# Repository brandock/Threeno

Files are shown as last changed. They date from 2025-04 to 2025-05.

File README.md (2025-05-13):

# Threeno

**Threeno** is a family of through-hole, Arduino-compatible boards that came out of my own learning process as I dove deeper into low-power wireless sensor nodes. These boards were inspired by the amazing work of Jean-Claude Wippler (JeeLabs), Felix Rusu (LowPowerLab), the OpenEnergyMonitor project, Nathan Chantrell’s TinyTx, and many others. Threeno is not meant to replace any of those designs—rather, it's a personal attempt to bring together what I’ve learned from them into a format that helped me prototype and understand more deeply. They’ve been useful to me as learning tools and prototypes—and maybe they can help others explore this ecosystem, too.

I wanted a board I could use to explore this whole ecosystem—JeeLib, OpenEnergyMonitor, RFM69 radios, and the new AVR parts supported by Spence Konde's cores—but with a familiar Arduino Uno shield footprint. I didn’t want to rely on breadboards anymore. Too often, my breadboard connections were the reason things didn’t work. So Threeno took shape as a set of hand-solderable boards using plated-through-hole parts that anyone with a soldering iron could build and experiment with.

## Objectives

These design goals shaped where and how pins are broken out on the boards:

- **Familiarity**: Match the footprint of the Arduino Uno for compatibility with Uno shields and known layouts.
- **Pin Position Parity**: Line up SPI, Serial, I²C, and other common peripherals with their usual locations on the Uno.
- **Through-hole Focus**: Use PTH parts wherever possible to keep things accessible. (HopeRF radios are technically SMD, but easily hand-soldered.)
- **Proven Components**: Include parts and patterns from designs by JeeLabs, Low Power Labs, OpenEnergyMonitor, and TinyTx—such as the MCP1702 regulator and the multi-transceiver RFM footprint.
- **Stock Arduino Tooling**: Use standard Arduino board managers—no Threeno-specific tools required. ATmega328P boards use the built-in Uno target; AVR128DB28 and ATtiny84 boards use Spence Konde’s DxCore and ATTinyCore.
- **Onboard Radios**: Including the HopeRF transceivers on the board makes prototyping wireless sensors a lot easier. These parts are somewhat notoriously difficult to breadboard, so having it soldered on in a proven way takes the guess work out of that part of your prototype. Other boards, such as Felix Rusu's Moteino, also take this approach in compact and polished designs.
- **Low Power**: Use the techniques used by Rusu, JCW, and OpenEnergyMonitor to make the boards run at very low power, with single-digit uA achievable in deep sleep mode.

## Ecosystem

Threeno boards are designed to work naturally with:

- [**JeeLib**](https://github.com/jeelabs/jeelib) by Jean-Claude Wippler (JCW)
- [**OpenEnergyMonitor**](https://openenergymonitor.org/) by Glyn Hudson, Trystan Lea, Robert Wall, and many others
- [**LowPowerLab’s low-power IoT project ecosystem**](https://lowpowerlab.com) by Felix Rusu
- [**Arduino IDE**](https://www.arduino.cc/en/software) with these board cores:
  - [**DxCore**](https://github.com/SpenceKonde/DxCore) – for AVR DB series
  - [**ATtinyCore**](https://github.com/SpenceKonde/ATTinyCore) – for ATtiny84

## Threeno Alternatives

Threeno tries to fill a specific niche: a set of through-hole, hand-solderable boards with onboard radios that integrate smoothly into the JeeLib and OpenEnergyMonitor ecosystems. But depending on your needs, one of these other boards might be a better fit:

- [**Moteino**](https://lowpowerlab.com/guide/moteino/) – The original Arduino + transceiver board. If you want an Arduino UNO-compatible board with a HopeRF transciever onboard, if you were not interested in soldering your own board, and if you didn't need the classic Arduino board-shape, you would clearly choose a Moteino over a Threeno. Compact, preassembled, with a great set of shields and sketches. Part of an IoT ecosystem of its own, with a great user community and great support from Felix Rusu. You should probably just get a Moteino or two regardless. 
- [**JeeNode**](https://web.archive.org/web/20201130081805/https://jeelabs.org/docs/hardware/jnclassic/) – A classic by JCW. [You can use the JeeNode USB as a RF-to-serial gateway.](https://community.openenergymonitor.org/t/receiving-jeelib-classic-and-lowpowerlab-in-parallel/22563) JCW has numerous plugin boards with various parts and sensors. It is a clever system that is different than Arduino sheilds, and makes a ton of sense. I have a classic JeeNode and love it.
- [**Azduino**](https://azduino.com) – The latest and greatest AVR microcontrollers, on convenient breakout boards from Spence Konde, who is making the Arduino cores for them.
- [**ESP32/ESP8266**](https://en.wikipedia.org/wiki/ESP32) – Excellent for Wi-Fi/Bluetooth, though less ideal for ultra-low power, which is one of the goals of the Low Power Lab, the JeeNode, and the OpenEnergyMonitor ecosystems.
- [**EVB RFduino**](https://dwmzone.com/en/hoperf/67-657-hoperf-dk-evb-rfduino-board.html?gQT=1) - I don't know much about this board, but it is apparently an Arduino Uno-compatible board with HopeRF radio pre-assembled. So if you (a) needed the Uno footprint (so Moteino wasn't an option) (b) didn't need onboard SPI flash memory option (RFduino apparently lacks one) (c) didn't want to solder together your own kit, this might be a board to investigate.

Each of these brings something different to the table—Threeno just aims to make it easier for people (especially soldering hobbyists) to experiment in this space with familiar tools and components.

## Meet the Boards

### [Threeno Tx (ATmega328P)](ThreenoTx.md)
A classic 3.3V UNO-style board with onboard RFM69CW and FTDI or ISP programming.


### [Threeno Tiny Tx (ATtiny84)](ThreenoTinyTx.md)
Minimal and battery-friendly. Based on the ATtiny84, a nod to Nathan Chantrell’s TinyTx.


### [Threeno DB28 Tx (AVR128DB28)](ThreenoDB28.md)
A modern AVR with UPDI programming, MVIO, and Uno-compatible layout.
IMG_4648 (1)

## Getting the Boards

- **Download Eagle files** and generate Gerbers
- **Order from Seeed Fusion**
- **Use the BOM** to order parts from DigiKey or Mouser

Each board page includes soldering guides and full part lists.

## Useful Tools

- [**FlexyTx Shield**](https://lowpowerlab.com/shop/flexytx) – Mount and test RFM69CW radios easily
- [**Evil Mad Scientist ISP Shield**](https://shop.evilmadscientist.com/productsmenu/652) – For burning bootloaders to raw AVRs

## Developing with Threeno

Use Spence Konde’s Arduino cores:

- [DxCore](https://github.com/SpenceKonde/DxCore) – for AVR128DB28
- [ATtinyCore](https://github.com/SpenceKonde/ATTinyCore) – for ATtiny84/85

For ATmega328P-based boards, select “Arduino Uno” in the IDE.

## License

This project is licensed under the GNU General Public License v3.0.

You may copy, distribute, and modify this software under the terms of the GPLv3.

See the full license at: https://www.gnu.org/licenses/gpl-3.0.en.html

---

This project is a thank you to the makers who built the boards I learned from.

– Brandon Baldock

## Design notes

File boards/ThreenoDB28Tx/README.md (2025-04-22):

# ThreenoDB28Tx

→ **Why this board?**  _(fill in)_  
→ **Pin‑out philosophy**  _(fill in, or copy from Board‑X‑PinoutPhilosophy.md)_  
→ **Build steps**  `make gerbers` → order → solder → program → blink :)

| Quick links |
|-------------|
| [BOM & ordering notes](docs/BOM.md) |
| [Build guide](docs/Build.md) |
| [Programming steps](docs/Program.md) |
| [Variants](docs/Variants.md) |
| [Example sketches](firmware/) |

```text
hardware/   KiCad or Eagle files
firmware/   PlatformIO / Arduino sketches
docs/       Markdown docs (exported as wiki or GitHub Pages)
```

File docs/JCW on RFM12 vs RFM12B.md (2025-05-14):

This article by RCW is interesting because he contends that the RFM12B won't be damaged by 5V. 

It can be found [here](https://web.archive.org/web/20210924000509/https://jeelabs.org/2009/05/06/rfm12-vs-rfm12b-revisited/index.html).

It is a follow-up to an initial article (also below) that can be found [here](https://web.archive.org/web/20210923233828/https://jeelabs.org/2009/04/29/rfm12-vs-rfm12b/index.html).

----------------

## RFM12 vs RFM12B – revisited ##
_In AVR, Hardware on May 6, 2009 at 00:01_

Now that the RFM12 is [working](https://jeelabs.org/2009/04/29/rfm12-vs-rfm12b/index.html), here’s the list of differences between RFM12 and RFM12B I’ve come across:

- The RFM12 works up to 5V, the RFM12B only up to 3.8V (but it won’t be damaged by 5V).
- The RFM12 needs a pull-up resistor of 10..100 KΩ on the FSK/DATA/nFFS pin, the RFM12B doesn’t.
- The RFM12 can only sync on the hex “2DD4” 2-byte pattern, the RFM12B can sync on any value for the second byte, not just D4.

More differences, found by Reinhard Max:

- The B version can be set to a single sync byte.
- The “PLL setting command” (CCxx), which only exists on the RFM12B.
- Different values for RX sensitivity and TX output power.
- A slightly different formula to calculate the time of the Wake-Up Timer.

Here is the back of the module, RFM12 on the left, RFM12B on the right:



_(these also happen to be for different frequency bands, as you can see)_

And here is the front view, with RFM12 on the _right_ and RFM12B on the _left_ this time:



The RFM12 unit on the right has a pull-up resistor added on top – note also the exposed pads at the top.

Note how the alignment of the solder pads on the JeeNode PCB is a bit off – these are v1 PCB’s, the v2 PCB’s have better alignment.

## RFM12 vs RFM12B ##
_In AVR, Hardware on Apr 29, 2009 at 00:01_

Here’s an RFM12 433 MHz module from Pollin, hooked up to an Arduino Duemilanove:



One major difference between the RFM12 and the RFM12B is that the RFM12 can run at 5V, whereas the maximum operating voltage for the RFM12B is 3.8V (it can withstand up to 6V, which is good to know).

Alas, there seems to be some other difference which eludes me, because the RFM12 hooked up in the above picture only seems to be able to send. The RF12 demo code, which works fine for send and receive on RFM12B’s, seems to do something wrong. Same behavior with another RFM12 module – so it looks like this is not due to a broken module. Send works, but nothing is coming in other than occasional garbage data.

The transmit part works fine when sending to an RFM12B, also in OOK mode: the RFM12 successfully controls both 433 and 868 MHz units (KAKU and FS20, respectively). _But as packet receiver for other RFM12 or RFM12B modules … no joy so far._

Weird. Tips, anyone? Please let me know.

**Update** – Thanks to R. Max’s comment below, the problem has been solved: the RFM12 does not support arbitrary 2-byte sync patterns, _it has to be 0x2D + 0xD4_ – then it works fine!

**Update 2** – _See also the [RFM12 vs RFM12B revisited](https://jeelabs.org/2009/05/06/rfm12-vs-rfm12b-revisited/index.html) page for a list of differences._

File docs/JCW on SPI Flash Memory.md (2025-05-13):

Some Threeno Tx boards have the option of onboard SPI flash memory, for compatibility with Moteino firmware and over-the-air programming developed by Felix Rusu of LowPowerLab.

JCW wrote in his blog about SPI flash memory, and I found it instructive, so I repost it here. You can also find it [here](https://web.archive.org/web/20221230224953/https://jeelabs.org/2015/04/15/dataflash-via-spi-2/index.html).

## Dataflash via SPI ##
_In Book on Apr 15, 2015 at 00:01_

One of the things I’m going to need at some point is additional flash memory. Since the simplest way these days to add more memory is probably via SPI, that’s what I’ll use.

This week’s episode is about connecting an SPI chip, implementing a simple driver, code re-use, the hidden dangers of solderless breadboards, and point-to-point soldering:



Hooking up a dataflash chip – Wed
Accessing SPI memory – Thu
Too much capacitance is bad – Fri
Soldering one-off SMD circuits – Sat
The end result is several megabytes of extra storage, using only 4 I/O pins. Data logger? Serial port audit? Storage for audio, video, images? Your next novel? _It’s all up to you!_

Hooking up a dataflash chip
Flash memory has taken over the world, covering an amazing range of memory needs:

- microcontrollers: _kilobytes_
- dataflash chips: _megabytes_
- USB- and (µ)SD cards: _gigabytes_
- SSDs in laptops and servers: _terabytes_

They all maintain their contents for many years and can be erased and re-written tens of thousands of times. Long gone are the days of core memory and battery backed-up RAM.

Not only that, a tiny dataflash chip such as this one from Winbond costs less than €2:



That gets you up to 16 megabytes of non-volatile storage, and the data is available faster than most most µCs can read them, with SPI clock rates up to 100 MHz. When connected in “Quad-SPI” mode, some µCs can in fact access 4 bits in parallel, giving a read-access rate of over 50 _Mbyte_ per second. That’s _random_ access: no rotational or seek delays in sight!

Writing is another matter. Usually, data can be written in units from 1 byte to one “page” (256 bytes, typically). Programming will normally take between 1 and 5 milliseconds – this is several orders of magnitude slowdown compared to the above sub-µs read timing.

It gets worse: you can’t just write anything anywhere – you can only turn a “1” bit into a “0” bit when programming any part of memory. After that, flash memory needs to be _erased_ before re-programming it further. An erase cycle resets part or all of memory to 1’s.

The bad news? Erasure can only be done in _sectors_ (or _segments_) of 4 Kb, usually (as well as a few larger units, all the way up to a full chip-erase).

The _really bad_ news? Erasing a segment can often take some 100 ms, with a full chip erase sometimes requiring several _minutes!_ – and after many erasures, these times will increase. During this time, the flash chip will be _busy_ (though there are ways to suspend/resume it).

The exact specs differ somewhat between chip families and manufacturers.

But as with the RomVars implementation described earlier, we can use tricks to make this delay less important. The basic idea is to keep one or more “pre-erased” sectors available, and to start a new erasure when the amount of erased memory gets too low. This requires keeping track of what is in use, and “garbage collecting” sectors to remove unused gaps.

But first, let’s just hook up such an SPI dataflash chip, in this case the Winbond W25Q64 – a 64 Mbit chip, i.e. 8 MB. It can erase sectors of 4, 32, and 64 KB, as well as the entire chip.

It’s easier to do this with an LPC812 than an 8-DIP LPC810 with only 6 I/O pins: with the LPC810, 4 of these will be needed for SPI, making it hard to reserve the 4 I/O pins needed for uploading as well. Besides, the LPC812 (at least some models) supports two separate SPI peripherals – which makes it much simpler to interface to both dataflash and a radio:



Note the use of a _breakout board_ again, to allow using this SMD chip on a breadboard.

The pins (numbered in counter-clockwise order) are connected as follows:

- pin 1: /cs    : PIO0_13
- pin 2: dout   : PIO0_7
- pin 3: /wprot : not connected
- pin 4: gnd    : ground
- pin 5: din    : PIO0_3
- pin 6: clk    : PIO0_2
- pin 7: /hold  : not connected
- pin 8: vcc    : 3.3V

The write-protect and hold pins are not used, and have an internal pull-up.

Note that actual GPIO pin choices are fairly arbitrary, since we can connect them all up as needed through the LPC8xx’s _switch matrix_ (except PIO0_10 and PIO0_11).

PIO0_2 and PIO0_3 are reserved for SWD hardware debugging on power-up, so the SWD functionality needs to be disabled to allow re-using them as ordinary I/O pins.

It’s probably good to point out here that most dataflash memory chips can only work with voltages up to 3.6V (and some not even that). _These chips may not be connected to 5V!_

Next, we’ll need some code to handle the SPI communication and verify that it all works.

## Accessing SPI memory ##
SPI is easy to interface to. That’s because the signalling is quite simple:



There’s a _master_ side (in this case, the µC), which is in control of the ENABLE, CLOCK, and MOSI pins, and there’s a _slave_ side (the dataflash chip), which controls the MISO pin (but only when ENABLE is low).

When ENABLE goes low, the master puts bits on the MOSI (“master out, slave in”) pin, and toggles the clock to shift each bit out to the slave. At the same time, it listens on the MISO pin (you guessed it: “master in, slave out”) and shifts the same number of bits in.

Usually the master first needs to send one or more bytes, so it ignores what comes back during those initial clock cycles. Then, it sends out 0’s and toggles the clock pin further to read back what the slave puts on the MISO pin. When done, the ENABLE pin is set to “1” again. All very simple stuff, even in software.

Unlike I2C, this is not a pure “bus”, in the sense that you can’t simply add more chips in parallel. Well, three of the pins _can_ and should be connected in parallel to all the slaves, but each slave will need a _separate_ ENABLE pin. In this example, there’s just one slave.

Most µCs have hardware support for SPI. This allows them to perform very fast signalling, much faster than software would be able to toggle and read out pins.

In the LPC8xx, the maximum speed for the master is the same as the µC’s clock speed, i.e. 12 MHz on power up, and 30 MHz when the PLL has been set up appropriately. Once set up, sending out and reading back two bytes using the LPC’s SPI hardware is trivial:

```c#
uint16_t xfer16 (uint16_t out) {
  addr()->TXDATCTL = SPI_TXDATCTL_FLEN(16-1) | SPI_TXDATCTL_EOT | out;
  while ((addr()->STAT & SPI_STAT_RXRDY) == 0)
    ;
  return addr()->RXDAT;
}
```

The LPC8xx hardware will set ENABLE to “0”, shift the data out and in using the CLOCK pin, and set ENABLE to “1” when done. At 12 MHz, this will all happen in less than 1.5 µS.

In the above example, three transfers can be seen: send 0x05 (result 0x00), send 0x35 (result 0x00), and send 0x9F (result 0xEF). These all access status and info registers.

SPI is a very common interconnect mechanism, and is also used by the RFM12/RFM69 wireless modules. In fact, we already have a _generic_ SPI bus driver in the embello repository on GitHub. It was designed to be easily re-used for different tasks.

And since SPI flash is a common mechanism, it’s a good idea to allow re-use of that code as well. Such an “SPI flash” driver can also be found on GitHub. Note that the SPI _bus_ driver is LPC8xx specific, but the SPI _flash_ driver built on top is not – it merely embodies the logic specific to the dataflash chip we’re using, _not_ how to talk to it for a particular µC.

With this code, we can now easily access our dataflash memory, using code such as:

```c#
#include "spi_flash.h"

SpiFlash<SpiDev0> spif;

int main () {
  ...
  spif.init();
  printf("0x%x\n", spif.identify());
  ....
  spif.eraseSector(...);
  spif.program(...);
  spif.read(...);
  ...
}
```

The SpiFlash<SpiDev0> is a C++ template notation, saying: define an object of the SpiFlash class, _specialised_ to use the SpiDev0 class as its bus access mechanism. Where SpiDev0 is in turn shorthand for SpiDev<0>, i.e. use the SPI0 hardware interface, of the two present in the LPC812 we’re using.

A simple test application can be found here. It erases a few sectors, programs a few pages, and then reads back the data a few times.

So, in _theory_, this stuff is trivial. We should expect this to work perfectly, right?

_Yes and no_… the “Channel 0” pin in the image above is a dangling wire, which happened to be attached to the 8-bit logic analyser (a €10 unit from eBay). Surprisingly, it returns some pulses. This is worrying – we seem to be picking up _stray_ signals from nearby wires.

_As you’ll see, there is some trouble ahead due to this and other unexpected side-effects._

## Too much capacitance is bad ##

The test code for the SPI flash erases sectors 0..9 (i.e. the first 40 KB), and then programs some values into the first 10 _pages_ (i.e. bytes 0..2559). Each page gets three values: N * 11, N * 22, and N * 33 – some of these values will end up different due to 8-bit truncation.

This is what a _good_ read-back of the first 11 pages should look like:

    #0: 0,0,0 @ 491 ms
    #1: 11,22,33 @ 493 ms
    #2: 22,44,66 @ 495 ms
    #3: 33,66,99 @ 496 ms
    #4: 44,88,132 @ 498 ms
    #5: 55,110,165 @ 501 ms
    #6: 66,132,198 @ 503 ms
    #7: 77,154,231 @ 505 ms
    #8: 88,176,8 @ 507 ms
    #9: 99,198,41 @ 509 ms
    #10: 255,255,255 @ 511 ms

The last value on each line is the clock time since startup (SPI is not running at max speed). Also, the last line shown above comes from a page which has been erased but not written to, and as you can see, it’s all 0xFF’s, i.e. all “1” bits.

Unfortunately, the _real_ test results are not consistent at all on the breadboard setup:

    #0: 0,128,128 @ 608 ms
    #1: 0,128,128 @ 610 ms
    #2: 0,128,128 @ 612 ms
    #3: 33,66,227 @ 614 ms
    #4: 44,216,132 @ 616 ms
    #5: 55,110,165 @ 618 ms
    #6: 66,132,198 @ 621 ms
    #7: 77,154,231 @ 623 ms
    #8: 88,176,136 @ 625 ms
    #9: 99,198,169 @ 627 ms
    #10: 255,255,255 @ 629 ms

Keep in mind that this is serial data, and for some reason, MISO is receiving all 0’s, or a 1 followed by 0’s on those first three pages. So some signal levels seem to be _wrong!_

The problem must be either a voltage or a timing issue, since the chip is clearly working, i.e. receiving and returning data “more or less” as expected. The software too must be doing its thing – again, we’d never be able to erase / program / read back _anything_ if it weren’t!

This is a typical hardware issue. In fact, it’s a fundamental electrical problem. Digital logic is all about 1’s and 0’s, and we’re not seeing the values we expect. At least not consistently.

An intermittent problem with voltage / timing (in reality, it’s _both_) points to an issue with “signal integrity”. What _should_ be a clean pulse on the wire, isn’t. It can be quite tricky to analyse such problems – even just hooking up an oscilloscope probe might affect the signal.

But there’s one easy way to find out if we’re looking in the right direction: build the same circuit again with a substantially different electrical configuration and see how it compares:



As you can see, this dataflash chip was soldered directly onto the back of an LPC812 board (from [eBay](https://web.archive.org/web/20230401203300/http://www.ebay.com/itm/151628723373)). And sure enough: it works flawlessly, at full 12 MHz speed. _Bingo!_

_So what’s going on here?_

It turns out that the culprit is the combination of a high-speed dataflash chip and our solderless breadboard. From the Winbond W25Q64 datasheet:



The maximum specified load capacitance is only 30 pF: these SPI slave chips are meant to be placed very close to the SPI master, on a PCB with short and straight traces.

A solderless breadboard is a horrible way to connect high-speed signals (both analog and digital), due to the _parasitic_ capacitance. Think about it: lots of little electrical connectors, all running in parallel and right next to each other – what a great way to create capacitors!

Add to that the fairly long jumper wires, their parasitic inductance, and you end up with a signal path that really messes up the leading and falling edges of these signals. These chips are intended to run at up to 100 MHz, i.e. with pulse edges within _under 5 nanoseconds!_

By having to charge / discharge capacitors along the way and by going through wires which act as little inductances, we’re really messing with the signal shape, introducing “ringing” and “overshoot” on all its edges. Unintended signal reflections will make it even worse.

Here’s another hint that these dataflash chips can only generate very weak signals:



The output voltage levels are specified at currents of only 100 µA. That’s not a lot to overcome any _parasitic capacitance_, which our setup must be adding to the circuit.

There are two conclusions to be drawn from all this:

1. solderless breadboards are not suitable for _every_ circuit, even simple ones  
2. we don’t always need high-end equipment to diagnose and fix such issues

Note that even with a 50..200 MHz oscilloscope it’s not always easy to figure this out. Such very high-speed signals will not render accurately, but worse still is that the probe itself is likely to affect these results: a standard scope probe adds 10..15 pF to the circuit! A high-end low-capacitance active FET probe would be needed, costing more than the scope itself.

_But the good news is that we’ve identified the issue and found a first workaround._

## Soldering one-off SMD circuits ##

Now that we’re running up against the limitations of solderless breadboards, it’s time to find alternative ways of constructing electronics circuits. And in this day and age, there’s really only one mainstream approach worth pursuing: _point-to-point soldered wires._

There are many ways to solder together components. It’s all about addressing the issue of mechanical stability, as well as taking care of the electrical connections, evidently:



This impressive image comes from [a Czech website](https://web.archive.org/web/20230401203408/http://www.valachnet.cz/lvanek/diy/old_story/index.html). It shows how to make a Z80-based computer, as built in the 1980’s. Point-to-point soldering has been around for a while.

We’re not going to be quite as ambitious, but we can re-use the same technique today to construct a small board with an SPI dataflash chip on it, piggy-backed onto an LPC810.

The first step is to mechanically fix the chip in place – using the VCC (8) and GND (4) pins:



The rest of the pins have been bent up a bit, to avoid touching the pads which are a bit too large for this SMD component. Then we use “Kynar wire-wrap” wire for all connections:

https://web.archive.org/web/20241027051047im_/https://jeelabs.org/wp-content/uploads/2015/04/DSC_50201.jpg

This type of wire is available in different size spools at a very reasonable cost. The core is 0.01″ in diameter and has a resistance of about 0.3 Ω/m. Some important benefits are that the insulation is easy to remove, the wire solders very easily, and perhaps most important of all: the insulation can withstand brief contact with a hot soldering iron tip without immediately melting away.

Some links to Conrad’s Dutch web-shop, also available in most other European countries:

- 15 m of wire-wrap wire, it’s available in many colours – [606632](https://web.archive.org/web/20230401203408/https://www.conrad.nl/nl/wikkeldraad-wrapping-1-x-005-mm-zwart-conrad-93014c351-15-m-606632.html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)
- side-strip pliers, suitable for these thin types of insulated wires – [1312388](https://web.archive.org/web/20230401203408/https://www.conrad.nl/nl/ck-t3893-1312388.html)
- another kind of wire stripper, mostly suitable for end-stripping – [821746](https://web.archive.org/web/20230401203408/https://www.conrad.nl/nl/jokari-pws-plus-001-micro-striptang-pws-plus-001-012-040-mm-awg-36-26-kabels-met-een-buitenmantel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)

You might think that stripping such short bits of wire is difficult, but here is a video of an interesting approach. It strips the insulation in the middle and then shifts it around to make precisely controlled pieces of wire – while still being easy to hold and solder:

- [https://youtu.be/7a3dA4r8rxc?t=400](https://web.archive.org/web/20230401203408/https://youtu.be/7a3dA4r8rxc?t=400)

No need to watch all 10 minutes, the first 1:30 min at the time linked to above is enough.

As for the pcb material to use for this: in the above images, a low-cost single-sided paper-based “perf-board” was used, mainly because it’s very easy to break and cut into small pieces as needed. The trouble with single-sided copper plating on this type of material is that the pads will easily come loose when heated too much, or when pushed on.

A much better option is FR4 with “plated-through” holes and pads: first of all, it supports soldering on both sides, i.e. placing components on one side and soldering wires on the other side, but also such plated-through holes are a lot sturdier to solder on and to handle considerable amounts of mechanical force. This is most useful for headers, switches, etc.

A drawback of FR4, which is commonly used for PCBs, is that it’s much harder to cut. A small hacksaw could be used, or – with some patience – you can make a series of cuts with a Stanley knife on _both_ sides, and then wiggle and break the board in half with flat pliers:



This option is more durable, and will withstand lots of soldering and re-soldering.

For [another](https://web.archive.org/web/20230401203408/http://elm-chan.org/docs/wire/wiring_e.html) – _astonishing_ – technique, check out this [demo board](https://web.archive.org/web/20230401203408/http://elm-chan.org/docs/wire/wcd.jpeg) and [10-minute video](https://web.archive.org/web/20230401203408/https://www.youtube.com/watch?v=i5MNLTc7YhY). This uses “magnet wire” with a clear insulation that melts _and_ fluxes the wire at ≈ 400°C.

_Who says one-off electronic designs have to end up as quick-and-dirty builds?_

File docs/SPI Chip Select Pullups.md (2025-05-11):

## Pull-ups on Threeno Chip-Select Lines

On all Threeno boards you’ll find a 10 kΩ pull-up resistor permanently tied to each SPI device’s _chip-select_ (CS) line.  

## Why a permanent pull-up on CS?

### 1. Avoid SPI-bus contention during AVR ISP programming  
On our ATmega328- and ATtiny84-based Threeno boards (ThreenoTx, ThreenoTinyTx), the MOSI/MISO/SCK pins double as the ICSP interface.  Without a pull-up, a floating CS line can be driven low by noise or by the bootloader sequence, causing the radio or Flash to drive MISO at the same time your ISP programmer is talking to the MCU—and that can corrupt programming or even “brick” the chip.

Read more [here](https://lowpowerlab.com/forum/rf-range-antennas-rfm69-library/rfm69-causes-atmega328p-to-brick-in-isp-mode-(solved)/)
And [here](https://lowpowerlab.com/forum/rf-range-antennas-rfm69-library/rfm69-causes-atmega328p-to-brick-in-isp-mode-(solved)/) in the LowPowerLab forum.

### 2. Protect SPI-Flash memory from accidental writes/reads  
On Threeno boards that have SPI-Flash memory installed, the same principle applies: a 10 kΩ pull-up holds the Flash-CS line _high_ until your code actively drives it low.  This ensures:

- The Flash never drives the bus when you’re not using it.  
- Bus contention cannot occur when multiple slaves share the SPI lines. In particular, the transciever cannot corrupt the flash memory while the MCU is busy booting up or getting programmed.  

## ThreenoDB28 and Chip Select
UPDI programming never touches MOSI/MISO/SCK—so there’s no ISP-vs-radio conflict. So we only need pull-ups to prevent contention between SPI devices themselves. If there is only one (flash-only or transceiver-only, with the other omitted) the pull-up resistors can be left off.

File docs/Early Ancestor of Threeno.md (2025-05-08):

This might be the earliest ancestor of the Threeno board. From JCW on December 11, 2008.

Also available here: https://web.archive.org/web/20221230225609/https://jeelabs.org/2008/12/11/good-rf-with-rfm12b/index.html

## Good RF with RFM12B
_In AVR, Software on Dec 11, 2008 at 15:38_

Yippie. Got a simple blinking LED demo running on RFM12B’s after lots of head-scratching. Had to understand ATmega’s SPI mechanism to get there, but these two boards now talk to each other over the air, uni-directionally:



That’s an Arduino Mini Pro (which runs at 3.3V internally, as does the RFM12B). Power comes from the FTDI cable, but with a special hack to drive the raw power input from it, not the default VCC connection. This way, the on-board 3.3V regulator is used to lower the voltage for both the MCU and the wireless module.

The other board is a bit of a mess, has the same Mini Pro, but some other stuff which is partly a left-over from earlier experiments:



Here a USB interface is used to provide 3.3V power. It’s functionally identical to the first board: with RFM12B’s the same setup can be used as transmitter or as receiver.

The top board is the receiver – its picture shows the green LED on, i.e. correct packet reception!

The hookup is very simple, just 5 wires between RF module and MCU, and 2 power pins / 1 pull-up / 1 antenna wire on the RF module is all it takes. The 5 wires are standard SPI plus an IRQ line:

- MOSI (MCU) –> SDI (RFM)
- MISO (MCU) <– SDO (RFM)
- SCK (MCU) –> SCK (RFM)
- SS (MCU) –> nSEL (RFM)
- PD2 (MCU) <– nIRQ (RFM)
  
It took some work to get the software working. The trouble with this stuff is that until you get both transmitter and receiver working properly, it all remains a bit hard to debug. And there are quite a few registers to set up on the RFM12B to make it do its magic.

But after some tweaking, the rfm12xmit and rfm12recv sketches for the Arduino IDE started working. First with bit-banged SPI coding, but then also with the ATmega168’s built-in SPI hardware. Which is nice, because all exchanges now take place at 1..2 MHz (i.e. 8..16 µsec per 16-bit command). All I/O with the RF module uses simple busy polling for now.

The RF range and quality of reception with the RFM12B is considerably better than my earlier 868 MHz AM setup. Packets now easily get across 3 layers of stone/concrete and all of them appear to be arriving properly.

**Update** – here’s the C source code for the xmit and recv sides.

**Update 2** – the connections for MISO and MISO as listed above were _reversed_ – many thanks to José Xavier for pointing this out. The text above has been fixed.

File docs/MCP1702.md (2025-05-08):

The voltage regulator used on Threeno boards is the MCP1702, based on the designs of JCW. Here is his article on the regulator's current draw from June 21, 2011. 

It can also be found here: https://web.archive.org/web/20230530204814/https://jeelabs.org/2011/06/21/mcp1702-current-draw/index.html

## MCP1702 current draw
_In Hardware on Jun 21, 2011 at 00:01_

The MCP1702 used in JeeNodes and other circuits here at JeeLabs is a nifty little voltage regulator. It’s not particularly good for high voltages (limited to about 13V), but it has a very low idle current. That’s very useful for low-power circuits, especially when trying to get months or even years of service out of one set of batteries.

Let’s find out how it’s performing. I’ve set up this little test circuit:



Well, it’s not really a test circuit at all – it’s in fact exactly what you need to use one of these things.

Putting 5V on the input (Vin), and leaving it a few minutes to settle, gives me a reading of 2.2 µA. Great, just what the specs say. It doesn’t really go up much with input voltage: 2.8 µA @ 12V. This is at no load.

With a 10 kΩ load, current draw rises to 338.1 µA, i.e. 330 µA for the resistor and about 8.1 µA for the regulator (assuming perfect calibration). That’s only 6 µA more, i.e. about 2% of the load.

Now let’s take the input voltage down, and see how this “low-drop” regulator behaves:

- 5.0 V -> 2.2 µA
- 4.0 V -> 2.2 µA
- 3.5 V -> 2.1 µA
- 3.3 V -> 2.1 µA
- 3.2 V -> 90.4 µA
- 3.1 V -> 84.1 µA
- 3.0 V -> 78.2 µA

_Whoa_… it sure doesn’t like being fed less voltage than it needs to supply a regulated output of 3.3V! The change is quite pronounced between 3.30 and 3.28V (I couldn’t get my power supply knob to adjust any more accurately).

For yesterday’s AA power board discussion that’s actually bad news, because it means that when the supply drops a mere 20 mV, it could cause the regulator to start wasting a fair amount of current (relatively speaking).

Let’s try something different: _no power on Vin, but power on Vout instead._

This simulates connecting a battery to the +3V pin, and bypassing the MCP1702 voltage regulator altogether. Evidently, it’s not a good idea putting much more than 3.3V on there, since now we’re reverse feeding the regulator, something not all regulators are happy with:

- 3.40 V -> 1000 µA
- 3.35 V -> 500 µA
- 3.30 V -> 90 µA
- 3.25 V -> 90 µA
- 3.20 V -> 90 µA
- 3.10 V -> 84 µA

The conclusion seems to be: _when using the AA Power Board in combination with a JeeNode, it might be better in certain cases to omit the regulator altogether if you’re aiming for minimal power consumption!_

It’s not enough to short the regulator’s Vin and Vout, it really has to be taken out of the circuit. Fortunately, you don’t have to disconnect _all three pins_ – just disconnect the ground pin (on the JeeNode v4..v6, that’s the one closest to the FTDI connector).

But if all you want to do is power the whole thing from some power source over 3.3V, such as a 3x AA battery pack or a LiPo battery, then all is fine… you’ll see that ultra-low 2.2 µA figure – as intended in this design.

Just beware of low voltages: _weird things do happen!_

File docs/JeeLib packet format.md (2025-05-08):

What is now known as the JeeLib Classic format was developed by JCW and discussed in his blog as early as 2008.

Since his blog is no longer available at jeelabs.org, here is a reprint of his article on the packet format of JeeLib RF12 from June 9, 2011. 

It can currently be found at https://web.archive.org/web/20230603171646/https://jeelabs.org/2011/06/09/rf12-packet-format-and-design/index.html.

## RF12 packet format and design
_In Software on Jun 9, 2011 at 00:01_

The RF12 library contains the code to support the RFM12B wireless module in an Arduino-like environment. It’s used for JeeNodes but also in several projects by others.

Here’s the general structure of a packet, as supported by the RF12 driver:


I made quite a few design decisions in the RF12 driver. One of the goals was to make the communication work in the background, so the driver is fully interrupt-driven. An important choice was to limit the packet size to 66 bytes of payload, to keep RAM use low and still allow just over 64 bytes of payload, enough to send data in 64-byte chunks with a _teeny_ bit of additional info.

Another major design decision was to support absolutely minimal packet sizes. This directly affects the power consumption, because longer packets take more time, and the longer the receiver and transmitter are on, the more precious battery power they will consume. For this same reason, the transmission bit rate is set fairly high (about 50 kbits/sec) – a higher rate means the same message can be sent in less time. A higher rate also makes it harder for the receiver to still pick up a good packet, so I didn’t want to push this to the limit.

This is how the RF12 driver can support really short packets:

- the network group is one byte and also doubles as second SYN byte
- the node ID is small enough (5 bits) to allow a few more header bits in the same byte
- there are only three header bits, as described in more detail in tomorrow’s post
- there is only room for _either_ the source node ID _or_ the destination node ID

That last decision is a bit unusual. It means an incoming packet can _only_ inform the receiver where it came from, _or_ define which receiver the packet is intended for – not both.

This may seem like a severe limitation, but it really isn’t: just add the missing info in the payload and agree on a convention so that the receiver can pick it up. All the RF12 does is enforce a truly minimal design, you can add any info you like as payload.

As a result, a minimal packet has the following format:



That’s 9 bytes, i.e. 72 bits – which means that a complete (but empty) packet can be sent out in less than 1.5 ms.

_Tomorrow, I’ll describe the exact logic used in the HDR byte, and how to use broadcasts and ACKs._

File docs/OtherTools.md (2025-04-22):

# Handy add‑ons

| Tool | Quick blurb |
|---|---|
| **FlexyTx Shield** | Spring‑socket RFM69 test jig that stacks on any UNO |
| **Evil Mad Scientist ISP Shield** | Swiss‑army 6‑pin AVR‑ISP breakout – perfect for raw MCUs |

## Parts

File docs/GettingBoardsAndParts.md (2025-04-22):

# Where to get the PCBs & parts

| Board | PCB Fabrication | MCU + Radio BOM | Pre‑built option |
|---|---|---|---|
| Threeno Tx | Seed Fusion / JLCPCB | ATmega328P‑AU + RFM69CW | *TBD* |
| Threeno Tiny Tx | OSH Park purple | ATtiny84A‑PU + RFM69CW | *TBD* |
| Threeno DB28 Tx | JLC 2‑layer ENIG | AVR128DB28‑AU + RFM69CW or RFM95 | *TBD* |

*STLs for 3‑D printable cases are tracked in* **tools/enclosures/**.

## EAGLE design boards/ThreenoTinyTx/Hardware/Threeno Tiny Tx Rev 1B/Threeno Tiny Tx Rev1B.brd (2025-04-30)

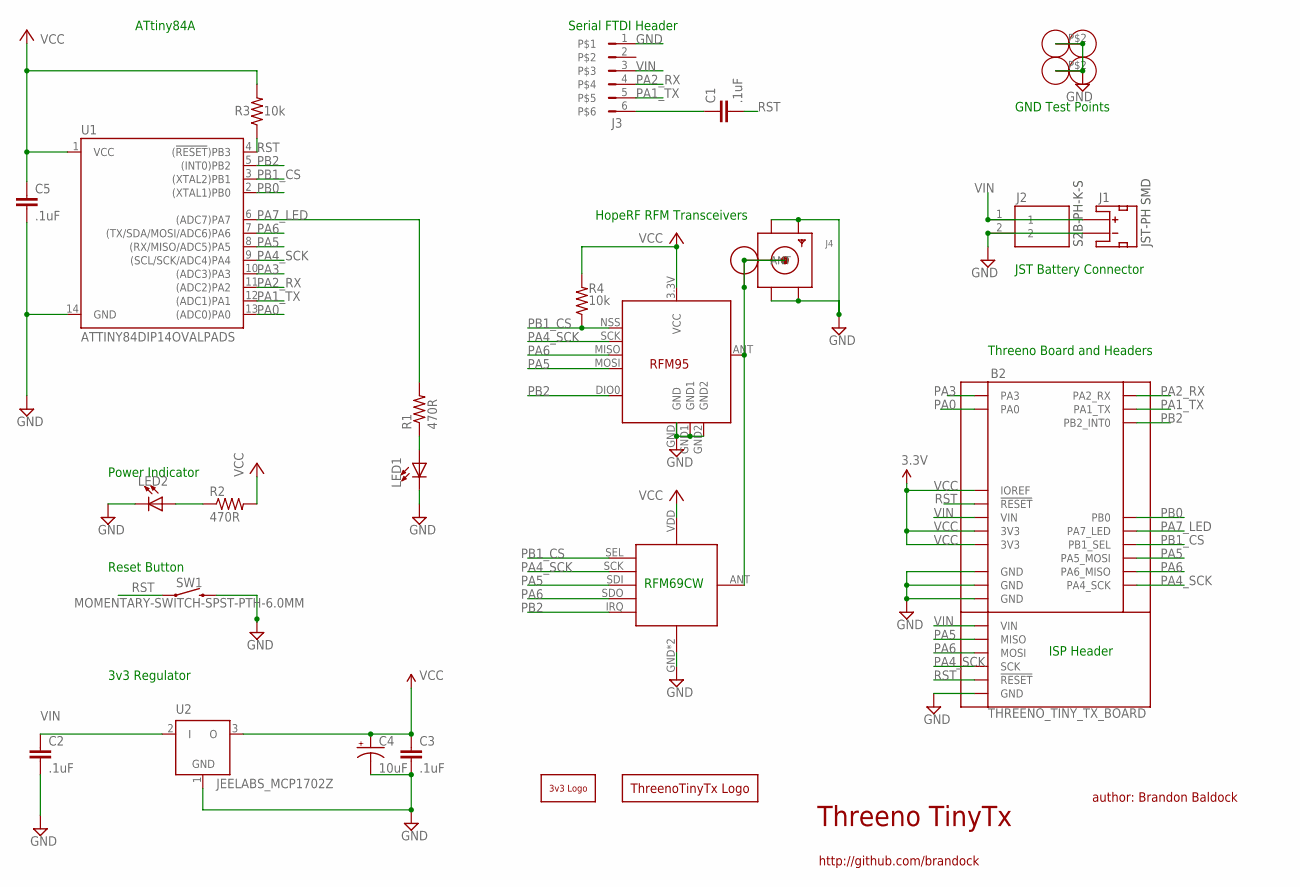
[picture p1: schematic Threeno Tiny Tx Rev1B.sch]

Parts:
B1: 3VTHREENO_BOTTOM_SILK
B2: THREENO_TINY_TX_BOARD
B3: THREENO_TINY_TX_LOGOTHREENO_TINY_TX_LOGO; THREENO_TINY_TX_LOGO
C1, C2, C3, C5: .1uF; C025-024X044-NO-MIDDLE-SILK
C4: 10uF; E1,8-4
J1: JST_2MM_MALE; JST-2-SMD
J2: S2B-PH-K-S; S2BPHKS
J3: FTDI; FTDI_ROUND_HEADER_SILK
J4: SMACONNECTOR_EDGE; SMA_EDGELAUNCH
J5: RFM12B_ANTENNA; RFM12B-ANTENNA
J6, J7: ALLIGATORCLIP-WIRELOOPTESTPOINT-WIRELOOP; ALLIGATORCLIP-WIRELOOP
LED1, LED2: LED-BRANDOCK3MM; LED3MM-BRANDOCK
R1, R2: 470R; 0204/7
R3, R4: 10k; 0204/7
RF1: RFM12B_MINPADS; RFM12B-MINPADS
RF2: RFM95LONGER; RFM95_LONGER
SW1: MOMENTARY-SWITCH-SPST-PTH-6.0MM; TACTILE_SWITCH_PTH_6.0MM
U1: ATTINY84DIP14OVALPADS; DIP14-OVALPADS
U2: JEELABS_MCP1702Z; JEELABS_TO92

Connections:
GND: B2.GND@1 (GND), B2.GND@2 (GND), B2.GND@3 (GND), B2.GND@ICSP (GND), C2.2, C3.2, C4.-, C5.2, J1.1 (-), J2.2, J3.1, J4.GND@1 (GND4), J4.GND@2 (GND3), J4.GND@3 (GND2), J4.GND@4 (GND1), J6.P$1, J6.P$2, J7.P$1, J7.P$2, LED1.K (C), LED2.K (C), RF1.GND, RF1.GND2 (GND), RF2.GND, RF2.GND1, RF2.GND2, SW1.3 (2), U1.14 (GND), U2.1 (GND)
unnamed: LED2.A, R2.1
unnamed: J4.P (ANT), J5.P$1, RF1.ANT, RF2.ANT
unnamed: C1.1, J3.6
unnamed: LED1.A, R1.1
PA0: B2.PA0, U1.13 ((ADC0)PA0)
PA1_TX: B2.PA1 (PA1_TX), J3.5, U1.12 ((ADC1)PA1)
PA2_RX: B2.PA2 (PA2_RX), J3.4, U1.11 ((ADC2)PA2)
PA3: B2.PA3, U1.10 ((ADC3)PA3)
PA4_SCK: B2.PA4 (PA4_SCK), B2.SCK@ICSP (SCK), RF1.SCK, RF2.SCK, U1.9 ((SCL/SCK/ADC4)PA4)
PA5: B2.MISO@ICSP (MISO), B2.PA5 (PA5_MOSI), RF1.SDI (SDI/MOSI), RF2.MOSI, U1.8 ((RX/MISO/ADC5)PA5)
PA6: B2.MOSI@ICSP (MOSI), B2.PA6 (PA6_MISO), RF1.SDO (SDO/MISO), RF2.MISO, U1.7 ((TX/SDA/MOSI/ADC6)PA6)
PA7_LED: B2.PA7 (PA7_LED), R1.2, U1.6 ((ADC7)PA7)
PB0: B2.PB0, U1.2 ((XTAL1)PB0)
PB1_CS: B2.PB1 (PB1_SEL), R4.1, RF1.SEL, RF2.NSS (SEL), U1.3 ((XTAL2)PB1)
PB2: B2.PB2 (PB2_INT0), RF1.IRQ, RF2.DIO0, U1.5 ((INT0)PB2)
RST: B2.!RESET!, B2.RESET@ICSP (!RESET!), C1.2, R3.1, SW1.1, U1.4 ((!RESET!)PB3)
VCC: B2.3.3V (3V3), B2.3.3V@2 (3V3), B2.IOREF, C3.1, C4.+, C5.1, R2.2, R3.2, R4.2, RF1.VDD, RF2.3.3V (VCC), U1.1 (VCC), U2.3 (O)
VIN: B2.VIN, B2.VIN@ICSP (VIN), C2.1, J1.2 (+), J2.1, J3.3, U2.2 (I)

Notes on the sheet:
Threeno TinyTx
author: Brandon Baldock
http://github.com/brandock
ISP Header
JST-PH SMD
S2B-PH-K-S
JST Battery Connector
RFM69CW
Power Indicator
Reset Button
3v3 Regulator
ATtiny84A
Threeno Board and Headers
HopeRF RFM Transceivers
Serial FTDI Header
GND Test Points

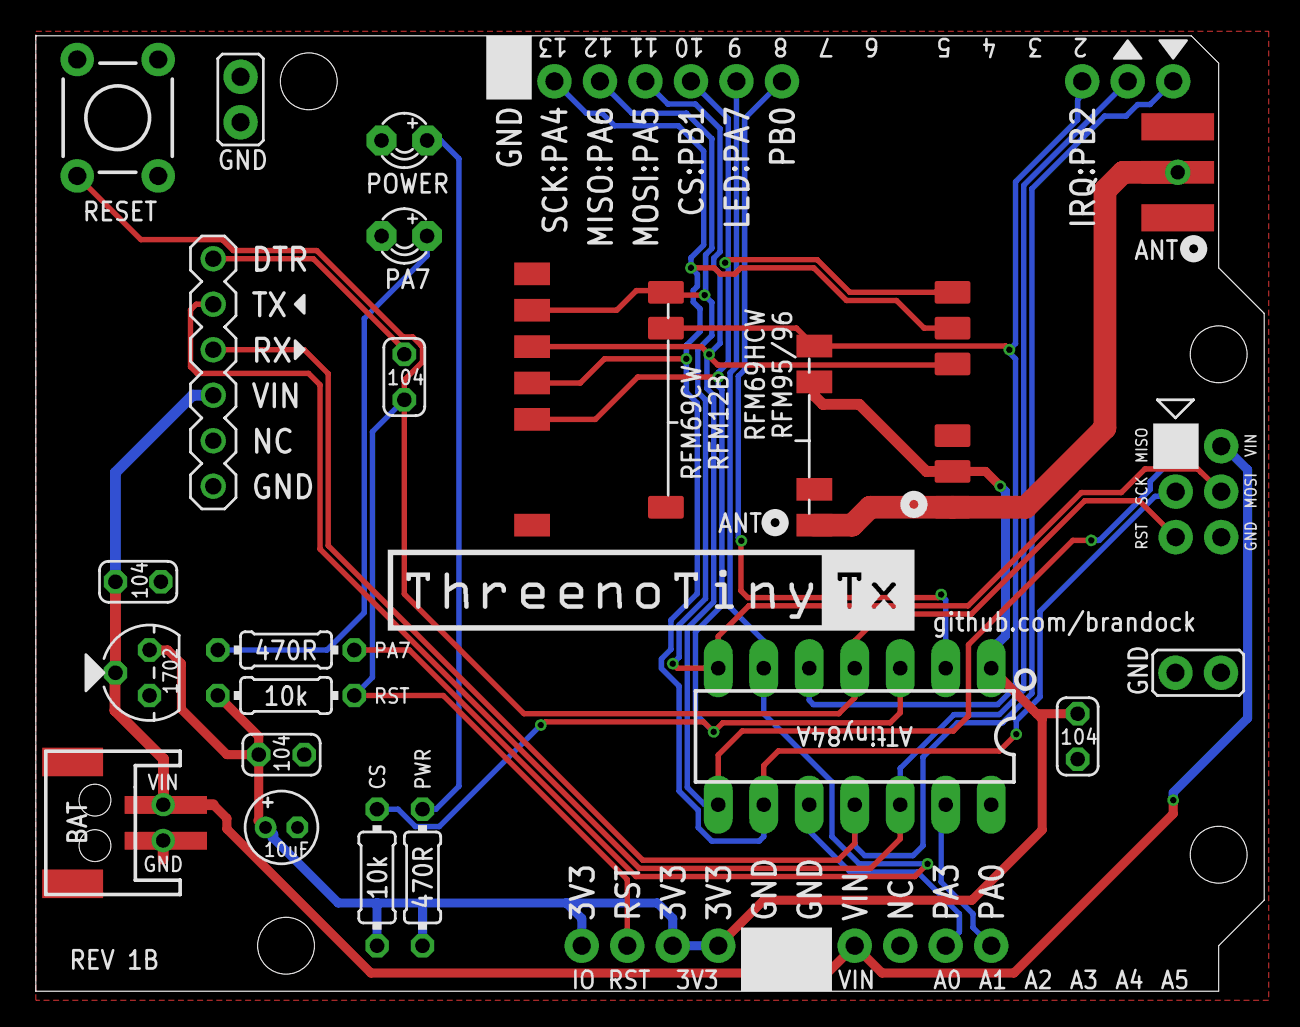
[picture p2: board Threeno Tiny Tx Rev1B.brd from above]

Board: 2 copper layers, 68.6 x 53.3 mm, 26 parts (0 on the bottom side), 19 nets.

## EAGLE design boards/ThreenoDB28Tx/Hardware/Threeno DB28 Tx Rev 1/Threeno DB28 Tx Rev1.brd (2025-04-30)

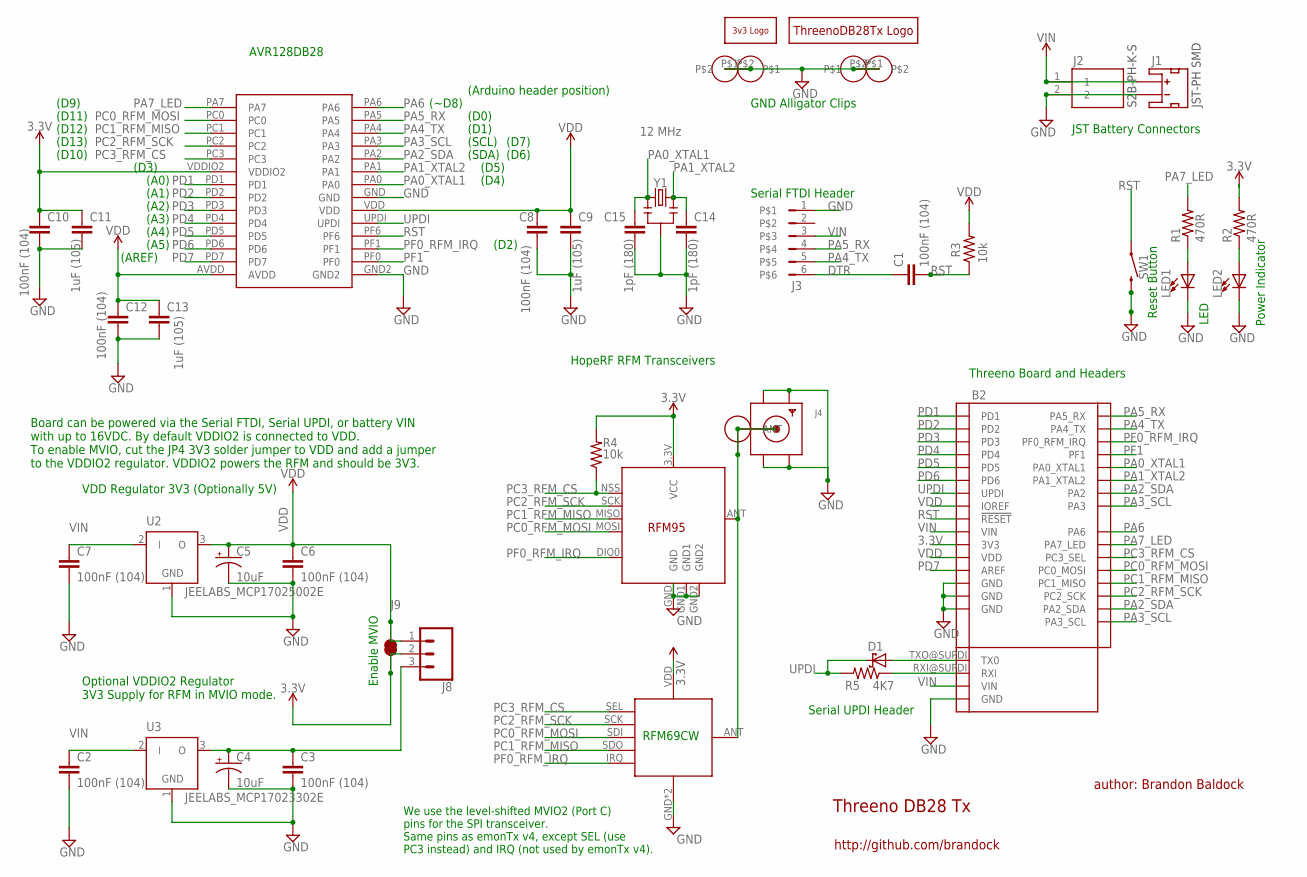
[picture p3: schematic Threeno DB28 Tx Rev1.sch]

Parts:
B1: 3VTHREENO_BOTTOM_SILK
B2: THREENO_DB28_TX_BOARD_V1.1
B3: THREENO_DB28_TX_LOGO
C1, C2, C3, C6, C7, C8, C10, C12: 100nF (104); C025-024X044-NO-MIDDLE-SILK
C4, C5: 10uF; E1,8-4
C9, C11, C13: 1uF (105); C025-024X044-NO-MIDDLE-SILK
C14, C15: 1pF (180); C025-024X044-NO-MIDDLE-SILK
D1: DIODE SCHOTTKY 30V 200MA DO35; DO41-7
J1: JST_2MM_MALE; JST-2-SMD
J2: S2B-PH-K-S; S2BPHKS
J3: FTDI; FTDI_ROUND_HEADER_SILK
J4: SMACONNECTOR_EDGE; SMA_EDGELAUNCH
J5: RFM12B_ANTENNA; RFM12B-ANTENNA
J6, J7: ALLIGATORCLIP-WIRELOOP
J8: 455-1750-1-ND; 1X03
J9: JUMPER-SMT_2_NC_TRACE_24_MIL_NO-SILK; SMT-JUMPER_2_NC_TRACE_NO-SILK_24_MIL
LED1, LED2: LED-BRANDOCK3MM; LED3MM-BRANDOCK
R1, R2: 470R; 0204/7
R3, R4: 10k; 0204/7
R5: 4K7; 0204/7
RF1: RFM12B_MINPADS; RFM12B-MINPADS
RF2: RFM95LONGER; RFM95_LONGER
SW1: MOMENTARY-SWITCH-SPST-PTH-6.0MM; TACTILE_SWITCH_PTH_6.0MM
U1: AVR128DB28; DIL28-3
U2: JEELABS_MCP17025002E; JEELABS_TO92
U3: JEELABS_MCP17023302E; JEELABS_TO92
Y1: 12 MHz; HC49US-OR-RESONATOR

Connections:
3.3V: B2.3.3V (3V3), C10.1, C11.1, J8.2, J9.2, R2.2, R4.2, RF1.VDD, RF2.3.3V (VCC), U1.VDDIO2
DTR: C1.1, J3.6
GND: B2.GND@1 (GND), B2.GND@2 (GND), B2.GND@3 (GND), B2.GND@SUPDI (GND), C2.2, C3.2, C4.-, C5.-, C6.2, C7.2, C8.2, C9.2, C10.2, C11.2, C12.2, C13.2, C14.2, C15.2, J1.1 (-), J2.2, J3.1, J4.GND@1 (GND4), J4.GND@2 (GND3), J4.GND@3 (GND2), J4.GND@4 (GND1), J6.P$1, J6.P$2, J7.P$1, J7.P$2, LED1.K (C), LED2.K (C), RF1.GND, RF1.GND2 (GND), RF2.GND, RF2.GND1, RF2.GND2, SW1.3 (2), U1.GND, U1.GND2, U2.1 (GND), U3.1 (GND), Y1.2
unnamed: LED2.A, R2.1
unnamed: J4.P (ANT), J5.P$1, RF1.ANT, RF2.ANT
unnamed: B2.RXI@SUPDI (RXI), R5.1
unnamed: B2.TXO@SUPDI (TX0), D1.A
unnamed: C3.1, C4.+, J8.3, U3.3 (O)
unnamed: LED1.A, R1.1
PA0_XTAL1: B2.PA0 (PA0_XTAL1), C15.1, U1.PA0, Y1.1
PA1_XTAL2: B2.PA1 (PA1_XTAL2), C14.1, U1.PA1, Y1.3
PA2_SDA: B2.PA2, B2.PA2|SDA (PA2_SDA), U1.PA2
PA3_SCL: B2.PA3, B2.PA3|SCL (PA3_SCL), U1.PA3
PA4_TX: B2.PA4|TX (PA4_TX), J3.5, U1.PA4
PA5_RX: B2.PA5|RX (PA5_RX), J3.4, U1.PA5
PA6: B2.PA6, U1.PA6
PA7_LED: B2.PA7 (PA7_LED), R1.2, U1.PA7
PC0_RFM_MOSI: B2.PC0 (PC0_MOSI), RF1.SDI (SDI/MOSI), RF2.MOSI, U1.PC0
PC1_RFM_MISO: B2.PC1 (PC1_MISO), RF1.SDO (SDO/MISO), RF2.MISO, U1.PC1
PC2_RFM_SCK: B2.PC2 (PC2_SCK), RF1.SCK, RF2.SCK, U1.PC2
PC3_RFM_CS: B2.PC3 (PC3_SEL), R4.1, RF1.SEL, RF2.NSS (SEL), U1.PC3
PD1: B2.PD1|A0 (PD1), U1.PD1
PD2: B2.PD2|A1 (PD2), U1.PD2
PD3: B2.PD3|A2 (PD3), U1.PD3
PD4: B2.PD4|A3 (PD4), U1.PD4
PD5: B2.PD5|A4 (PD5), U1.PD5
PD6: B2.PD6|A5 (PD6), U1.PD6
PD7: B2.PD7 (AREF), U1.PD7
PF0_RFM_IRQ: B2.PF0 (PF0_RFM_IRQ), RF1.IRQ, RF2.DIO0, U1.PF1
PF1: B2.PF1, U1.PF0
RST: B2.RESET@1 (!RESET!), C1.2, R3.1, SW1.1, U1.PF6
UPDI: B2.NC (UPDI), D1.C, R5.2, U1.UPDI
VDD: B2.VDD, B2.VDD|IOREF (IOREF), C5.+, C6.1, C8.1, C9.1, C12.1, C13.1, J8.1, J9.1, R3.2, U1.AVDD, U1.VDD, U2.3 (O)
VIN: B2.VIN, B2.VIN@SUPDI (VIN), C2.1, C7.1, J1.2 (+), J2.1, J3.3, U2.2 (I), U3.2 (I)

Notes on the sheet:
Threeno DB28 Tx
author: Brandon Baldock
http://github.com/brandock
Serial UPDI Header
JST-PH SMD
S2B-PH-K-S
JST Battery Connectors
RFM69CW
Power Indicator
Reset Button
Optional VDDIO2 Regulator 3V3 Supply for RFM in MVIO mode.
AVR128DB28
Threeno Board and Headers
HopeRF RFM Transceivers
Serial FTDI Header
(Arduino header position)
(D10)
(D9)
(D12)
(D11)
(D13)
(A0)
(A1)
We use the level-shifted MVIO2 (Port C) pins for the SPI transceiver. Same pins as emonTx v4, except SEL (use PC3 instead) and IRQ (not used by emonTx v4).
VDD Regulator 3V3 (Optionally 5V)
LED
(A2)
(A3)
(A4)
(AREF)
(SDA)
(SCL)
(~D8)
(D2)
(A5)
(D4)
(D6)
(D7)
Board can be powered via the Serial FTDI, Serial UPDI, or battery VIN with up to 16VDC. By default VDDIO2 is connected to VDD. To enable MVIO, cut the JP4 3V3 solder jumper to VDD and add a jumper to the VDDIO2 regulator. VDDIO2 powers the RFM and should be 3V3.
Enable MVIO

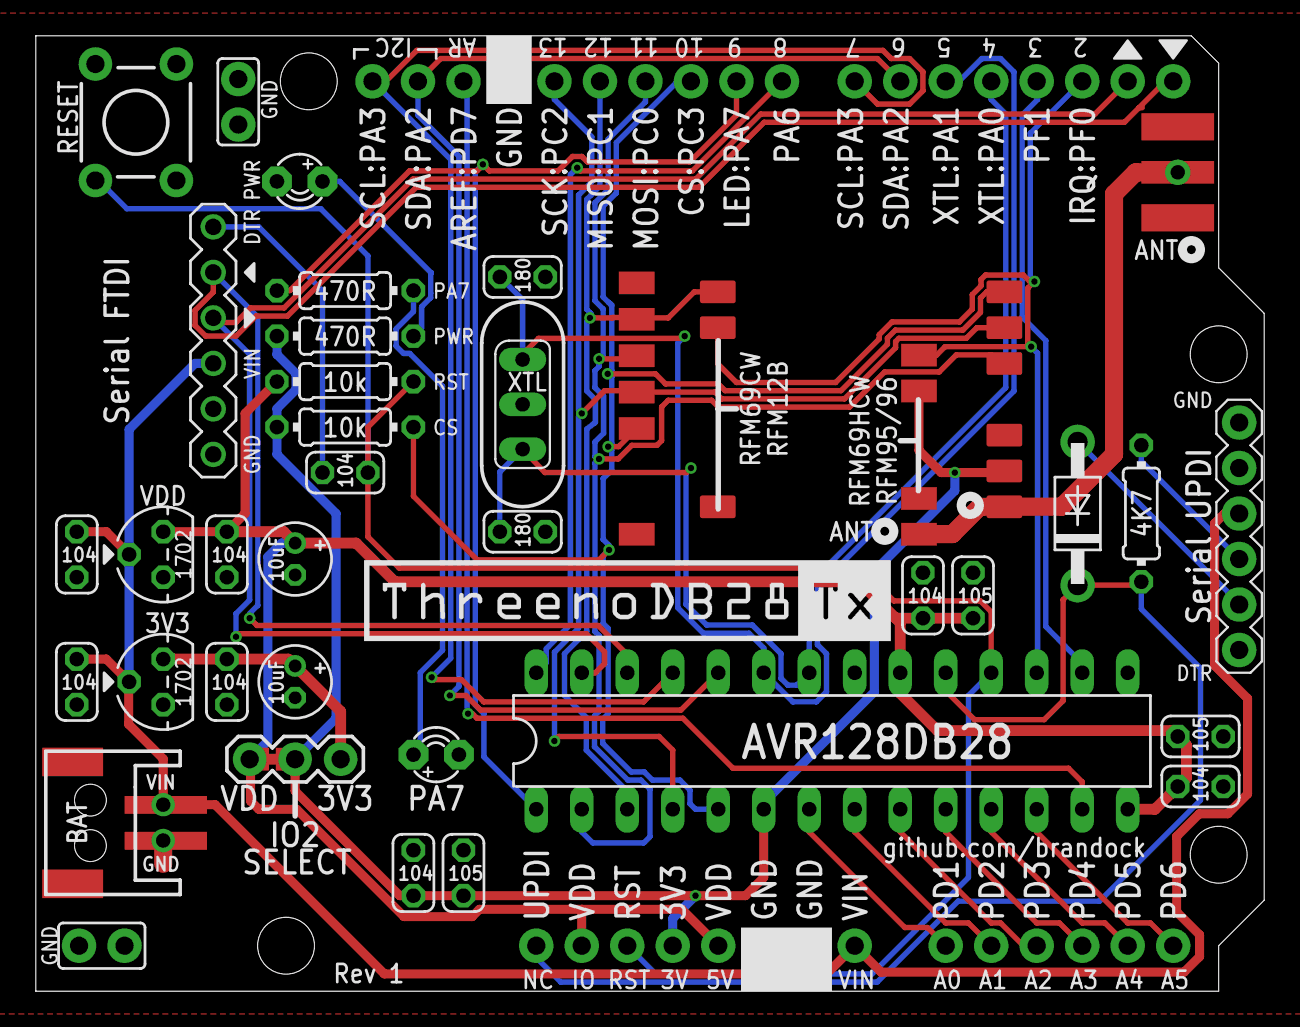
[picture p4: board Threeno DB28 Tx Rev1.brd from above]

Board: 2 copper layers, 68.6 x 53.3 mm, 42 parts (0 on the bottom side), 34 nets.

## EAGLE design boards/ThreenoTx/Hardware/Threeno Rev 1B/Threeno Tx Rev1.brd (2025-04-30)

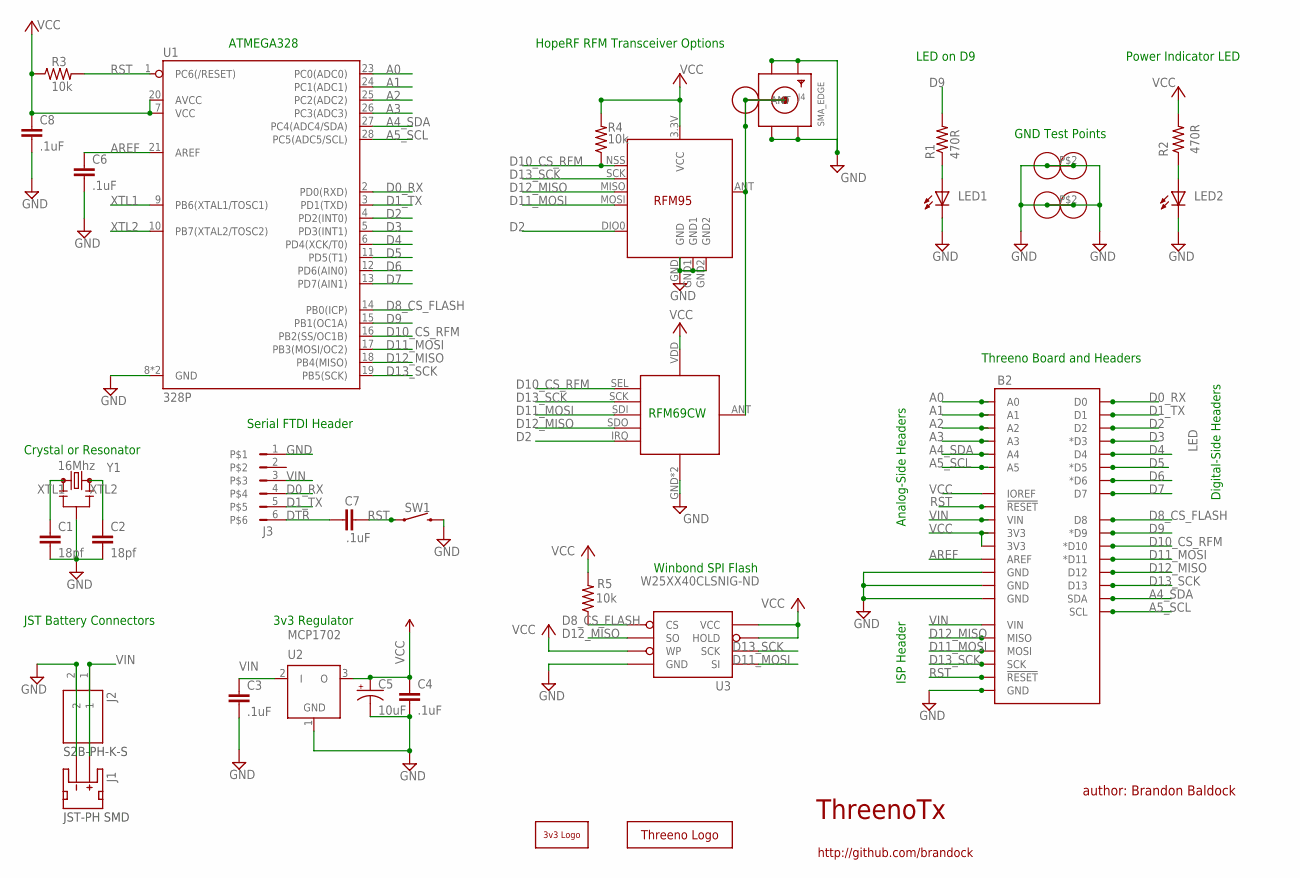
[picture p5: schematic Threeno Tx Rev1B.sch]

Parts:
B1: 3VTHREENO_BOTTOM_SILK
B2: THREENO_TX_BOARD3VTHREENO; THREENO_TX_BOARD
B3: 3VTHREENO_LOGO
C1, C2: 18pf; C025-024X044-NO-MIDDLE-SILK
C3, C4, C6, C7, C8: .1uF; C025-024X044-NO-MIDDLE-SILK
C5: 10uF; E1,8-4
J1: JST-PH-SMD; JST-2-SMD
J2: S2B-PH-K-S; S2BPHKS
J3: FTDI; FTDI_ROUND_HEADER_SILK
J4: SMA_EDGE; SMA_EDGELAUNCH
J5: RFM12B_ANTENNA; RFM12B-ANTENNA
J6, J7: ALLIGATORCLIP-WIRELOOP
LED1, LED2: LED; LED3MM-BRANDOCK
R1, R2: 470R; 0204/7
R3, R4, R5: 10k; 0204/7
RF1: RFM12B_MINPADS; RFM12B-MINPADS
RF2: RFM95LONGER; RFM95_LONGER
SW1: MOMENTARY-SWITCH-SPST-PTH-6.0MM; TACTILE_SWITCH_PTH_6.0MM
U1: 328P; DIP28-OVALPADS
U2: JEELABS_MCP1702Z; JEELABS_TO92
U3: AT25F512BJEDEC_3.9MM; SO08
Y1: 16Mhz; HC49US-OR-RESONATOR

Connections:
A0: B2.A0, U1.23 (PC0(ADC0))
A1: B2.A1, U1.24 (PC1(ADC1))
A2: B2.A2, U1.25 (PC2(ADC2))
A3: B2.A3, U1.26 (PC3(ADC3))
A4_SDA: B2.A4, B2.SDA, U1.27 (PC4(ADC4/SDA))
A5_SCL: B2.A5, B2.SCL, U1.28 (PC5(ADC5/SCL))
AREF: B2.AREF, C6.1, U1.21 (AREF)
D0_RX: B2.D0, J3.4, U1.2 (PD0(RXD))
D1_TX: B2.D1, J3.5, U1.3 (PD1(TXD))
D2: B2.D2, RF1.IRQ, RF2.DIO0, U1.4 (PD2(INT0))
D3: B2.D3 (*D3), U1.5 (PD3(INT1))
D4: B2.D4, U1.6 (PD4(XCK/T0))
D5: B2.D5 (*D5), U1.11 (PD5(T1))
D6: B2.D6 (*D6), U1.12 (PD6(AIN0))
D7: B2.D7, U1.13 (PD7(AIN1))
D8_CS_FLASH: B2.D8, R5.1, U1.14 (PB0(ICP)), U3.1_CS (CS)
D9: B2.D9 (*D9), R1.2, U1.15 (PB1(OC1A))
D10_CS_RFM: B2.D10 (*D10), R4.1, RF1.SEL, RF2.NSS (SEL), U1.16 (PB2(SS/OC1B))
D11_MOSI: B2.D11 (*D11), B2.MOSI@ICSP (MOSI), RF1.SDI (SDI/MOSI), RF2.MOSI, U1.17 (PB3(MOSI/OC2)), U3.5_SI (SI)
D12_MISO: B2.D12, B2.MISO@ICSP (MISO), RF1.SDO (SDO/MISO), RF2.MISO, U1.18 (PB4(MISO)), U3.2_SO (SO)
D13_SCK: B2.D13, B2.SCK@ICSP (SCK), RF1.SCK, RF2.SCK, U1.19 (PB5(SCK)), U3.6_SCK (SCK)
DTR: C7.1, J3.6
GND: B2.GND@1 (GND), B2.GND@2 (GND), B2.GND@3 (GND), B2.GND@ICSP (GND), C1.2, C2.2, C3.2, C4.2, C5.-, C6.2, C8.2, J1.1 (-), J2.2, J3.1, J4.GND@1 (GND4), J4.GND@2 (GND3), J4.GND@3 (GND2), J4.GND@4 (GND1), J6.P$1, J6.P$2, J7.P$1, J7.P$2, LED1.K (C), LED2.K (C), RF1.GND, RF1.GND2 (GND), RF2.GND, RF2.GND1, RF2.GND2, SW1.3 (2), U1.8 (GND), U1.22 (GND), U2.1 (GND), U3.4_GND (GND), Y1.2
unnamed: LED2.A, R2.1
unnamed: J4.P (ANT), J5.P$1, RF1.ANT, RF2.ANT
unnamed: LED1.A, R1.1
RST: B2.RESET@1 (!RESET!), B2.RESET@ICSP (!RESET!), C7.2, R3.2, SW1.1, U1.1 (PC6(/RESET))
VCC: B2.3.3V (3V3), B2.3.3V@2 (3V3), B2.IOREF, C4.1, C5.+, C8.1, R2.2, R3.1, R4.2, R5.2, RF1.VDD, RF2.3.3V (VCC), U1.7 (VCC), U1.20 (AVCC), U2.3 (O), U3.3_WP (WP), U3.7_HOLD (HOLD), U3.8_VCC (VCC)
VIN: B2.VIN, B2.VIN@ICSP (VIN), C3.1, J1.2 (+), J2.1, J3.3, U2.2 (I)
XTL1: C1.1, U1.9 (PB6(XTAL1/TOSC1)), Y1.1
XTL2: C2.1, U1.10 (PB7(XTAL2/TOSC2)), Y1.3

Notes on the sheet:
ThreenoTx
author: Brandon Baldock
http://github.com/brandock
ISP Header
JST-PH SMD
S2B-PH-K-S
JST Battery Connectors
RFM69CW
Power Indicator LED
3v3 Regulator
ATMEGA328
Threeno Board and Headers
Analog-Side Headers
Digital-Side Headers
HopeRF RFM Transceiver Options
Serial FTDI Header
GND Test Points
LED on D9
Crystal or Resonator
Winbond SPI Flash

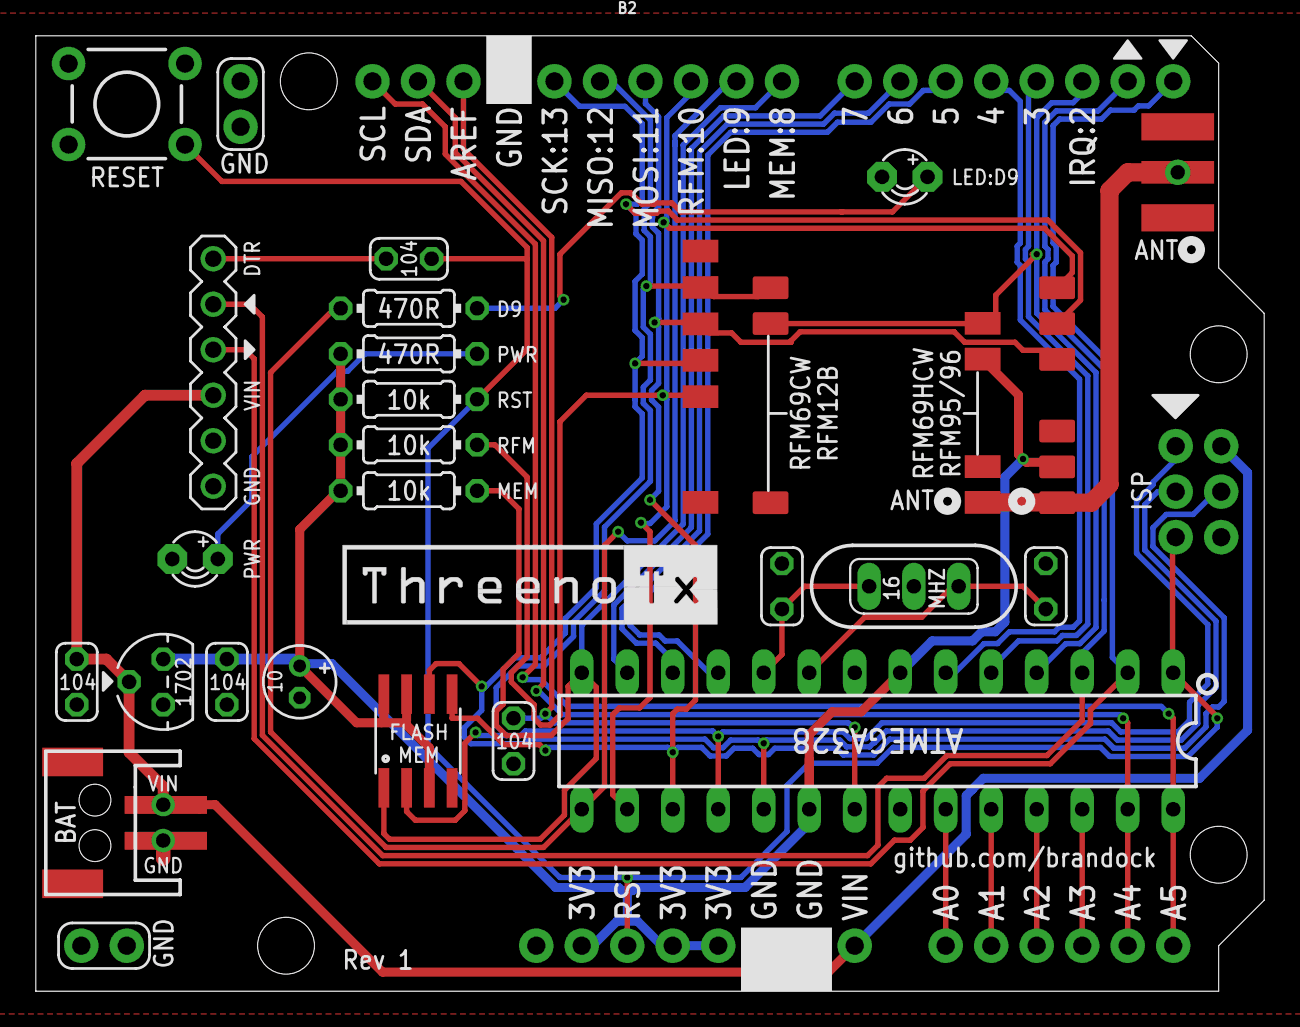
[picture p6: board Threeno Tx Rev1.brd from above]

Board: 2 copper layers, 68.6 x 53.3 mm, 31 parts (0 on the bottom side), 31 nets.

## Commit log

2025-04-22 Initial Threeno repo scaffold – boards, docs, ignore, licence
2025-05-11 Create SPI Chip Select Pullups.md
2025-05-12 Create JCW on SPI Flash Memory.md
2025-05-13 Update JCW on SPI Flash Memory.md

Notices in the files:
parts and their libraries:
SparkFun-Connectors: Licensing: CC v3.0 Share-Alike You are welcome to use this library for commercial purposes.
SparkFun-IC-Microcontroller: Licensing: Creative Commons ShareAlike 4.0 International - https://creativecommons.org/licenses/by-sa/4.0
